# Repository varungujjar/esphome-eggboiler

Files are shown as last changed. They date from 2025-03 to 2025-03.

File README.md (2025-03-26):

# ESP Home based Egg Cooker

  
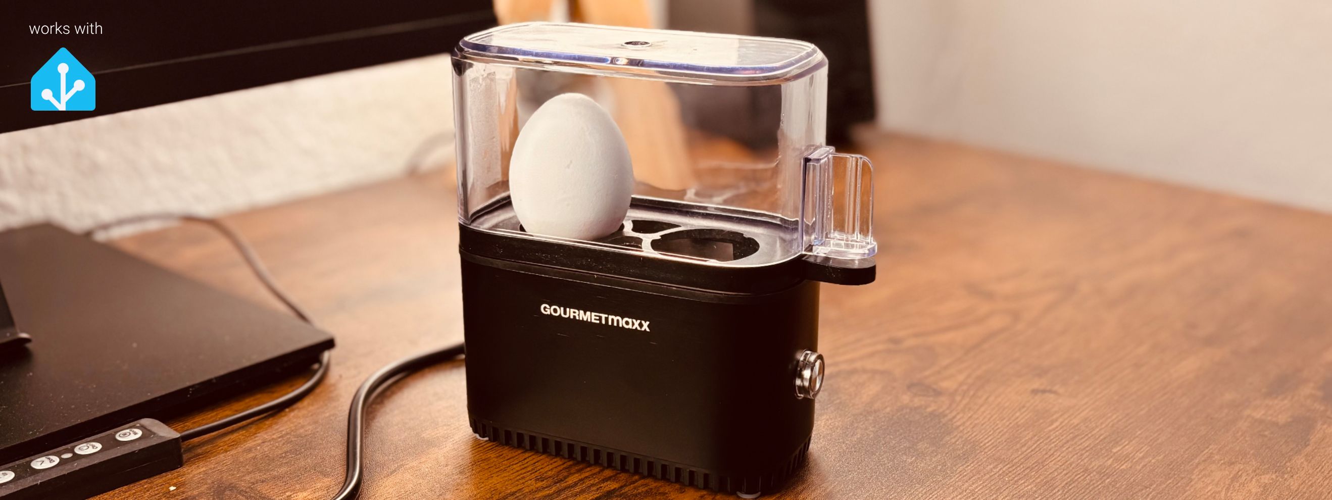
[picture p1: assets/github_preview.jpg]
App Screenshot
  

Smart Egg Cooker – Automate Your Breakfast Routine!

Upgrade your mornings with this intelligent Egg Cooker, designed to automate and perfect your breakfast routine. Equipped with a DS18B20 temperature sensor, it precisely monitors the boiling water, ensuring your eggs are cooked to perfection. A Piezo Buzzer alerts you when the cooker connects to WiFi and when your eggs are ready.

Seamlessly integrate it with Home Assistant for a smart home experience. Plus, with access to schematics and PCB Gerber files, you can fully customize and enhance its features to suit your needs.

Enjoy hassle-free, perfectly cooked eggs—every time!

## Features  

- Automate your morning breakfast routines with this egg cooker
- Temperature sensor using DS18B20 keeps track of the boiling water
- Piezo Buzzer plays sound when connected to Wifi & when egg is cooked
- Compatible with **Home Assistant** for seamless integration.  
- Access to schematics and PCB Gerber files.  
- Fully customizable for advanced features.  

## Requirements  

- **Home Assistant** (Standalone software version coming soon).  
- **USB-to-Serial Hardware** to program the ESP8266 12E.  
- **ESPHome Setup Guide**: [Getting Started with ESPHome](https://esphome.io/guides/getting_started_hassio.html).  

## Demo  
[Full Video](https://youtu.be/4700ta0FNh4).  

Follow us for more exciting projects and updates:  
  

## License  

This project is licensed under the **GPL-3.0 License**. [Learn More](https://www.gnu.org/licenses/gpl-3.0).

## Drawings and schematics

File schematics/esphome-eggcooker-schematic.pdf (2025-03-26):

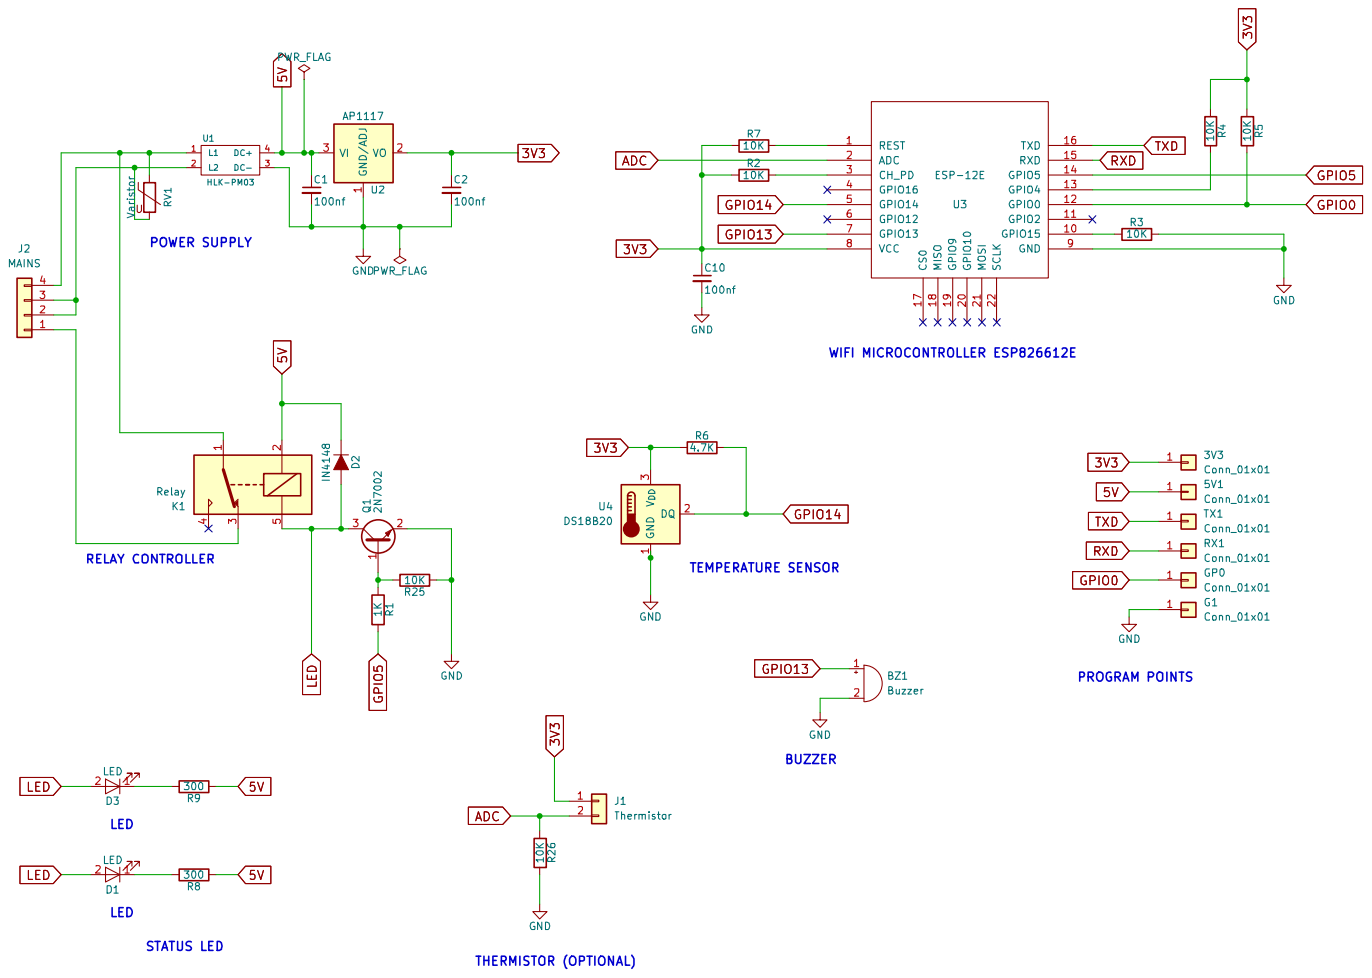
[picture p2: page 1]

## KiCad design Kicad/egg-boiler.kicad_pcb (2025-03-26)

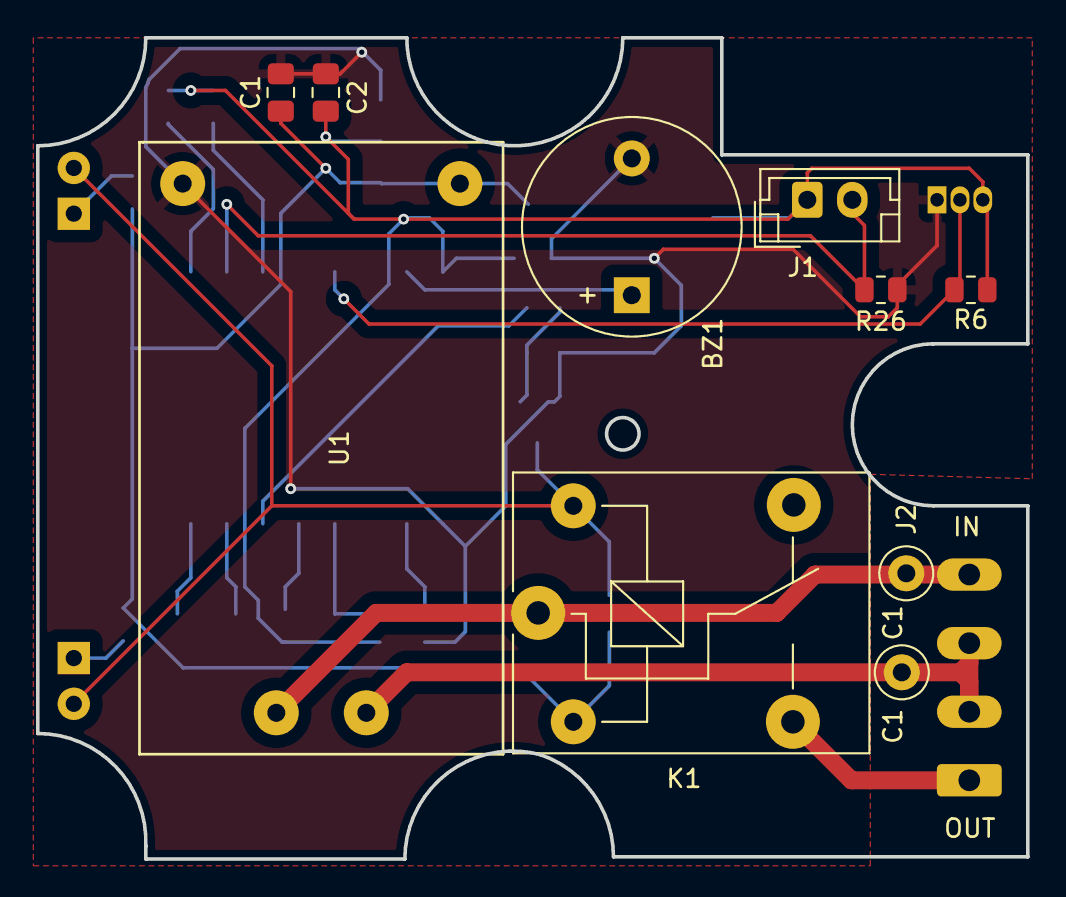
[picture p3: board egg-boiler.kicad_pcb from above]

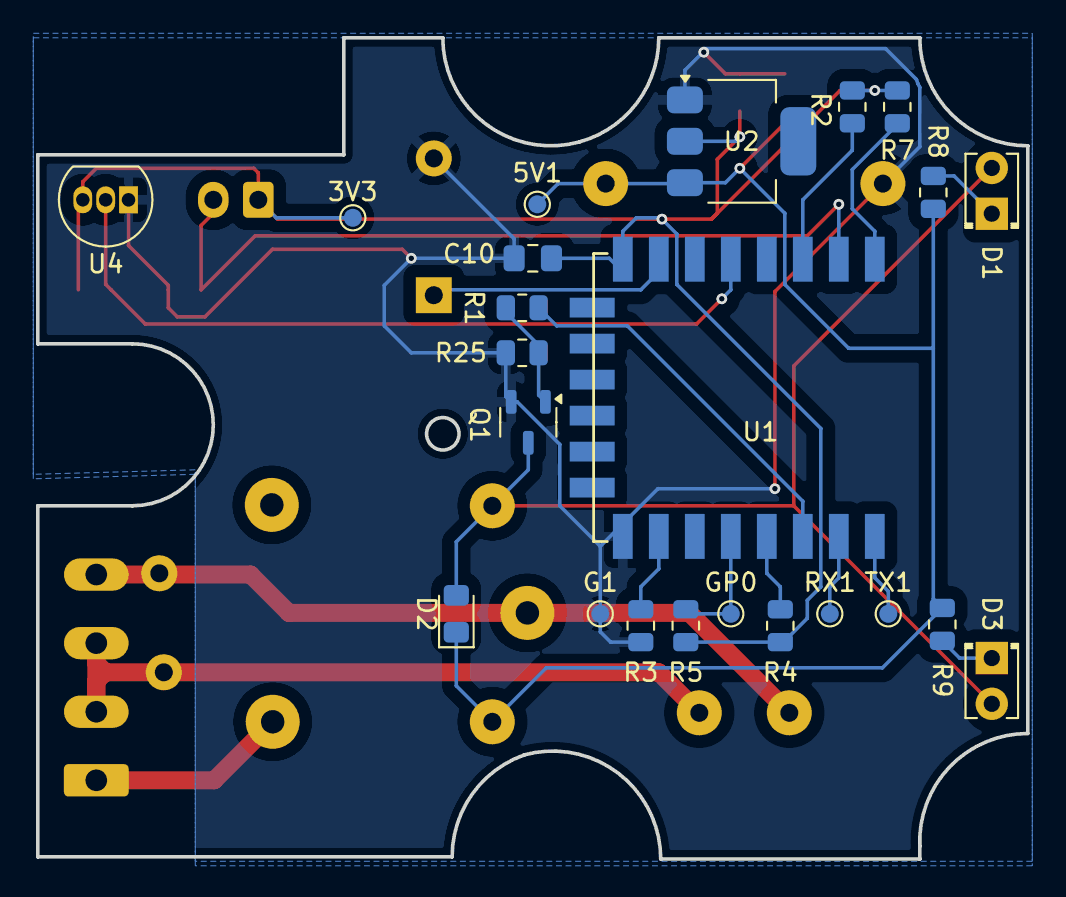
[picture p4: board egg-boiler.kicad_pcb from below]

Board: 2 copper layers, 55.0 x 45.6 mm, 34 parts (23 on the bottom side), 21 nets.

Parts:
3V3, 5V1: Conn_01x01; TestPoint_Pad_D1.0mm
BZ1: Buzzer; Buzzer_12x9.5RM7.6
C1, C1#2: C0; TestPoint_Loop_D1.80mm_Drill1.0mm_Beaded
C1#3, C2, C10: 100nf; C_0805_2012Metric_Pad1.18x1.45mm_HandSolder
D1, D3: LED; LED_D2.0mm_W4.0mm_H2.8mm_FlatTop
D2: IN4148; D_0805_2012Metric_Pad1.15x1.40mm_HandSolder
G1: Conn_01x01; TestPoint_Pad_D1.0mm
GP0: Conn_01x01; TestPoint_Pad_D1.0mm
J1: Thermistor; JST_EH_B2B-EH-A_1x02_P2.50mm_Vertical
J2: MAINS; PhoenixContact_MCV_1,5_4-G-3.81_1x04_P3.81mm_Vertical_Custom
K1: Relay; Relay_SPDT_SANYOU_SRD_Series_Form_C
Q1: 2N7002; SOT-23-3
R1: 1K; R_0805_2012Metric
R2, R3, R4, R5, R7, R25, R26: 10K; R_0805_2012Metric
R6: 4.7K; R_0805_2012Metric
R8, R9: 300; R_0805_2012Metric
RX1: Conn_01x01; TestPoint_Pad_D1.0mm
TX1: Conn_01x01; TestPoint_Pad_D1.0mm
U1: HLK-PM03; HLK-PM01
U1#2: ESP-12E; ESP-12E_SMD
U2: AP1117; SOT-223
U4: DS18B20; TO-92_Inline

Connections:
3V3: 3V3.1, C2.1, C10.1, J1.1, R2.1, R4.1, R5.1, R6.1, R7.1, U1#2.8 (VCC), U2.2 (VO), U4.3 (V_{DD})
5V: 5V1.1, C1#3.1, D2.1 (K), K1.2, R8.1, R9.1, U1.4 (DC+), U2.3 (VI)
ADC: J1.2, R26.1, U1#2.2 (ADC)
GND: BZ1.2 (-), C1#3.2, C2.2, C10.2, G1.1, Q1.2 (E), R3.2, R25.1, R26.2, U1.3 (DC-), U1#2.9 (GND), U2.1 (GND/ADJ), U4.1 (GND)
GPIO0: GP0.1, R5.2, U1#2.12 (GPIO0)
GPIO5: R1.2, U1#2.14 (GPIO5)
GPIO13: BZ1.1 (+), U1#2.7 (GPIO13)
GPIO14: R6.2, U1#2.5 (GPIO14), U4.2 (DQ)
LED: D1.2 (A), D2.2 (A), D3.2 (A), K1.5, Q1.3 (C)
unnamed: D1.1 (K), R8.2
unnamed: D3.1 (K), R9.2
unnamed: J2.1, K1.3
unnamed: J2.2, J2.3, U1.2 (L2)
unnamed: J2.4, K1.1, U1.1 (L1)
unnamed: Q1.1 (B), R1.1, R25.2
unnamed: R2.2, U1#2.3 (CH_PD)
unnamed: R4.2, U1#2.13 (GPIO4)
unnamed: R3.1, U1#2.10 (GPIO15)
unnamed: R7.2, U1#2.1 (REST)
RXD: RX1.1, U1#2.15 (RXD)
TXD: TX1.1, U1#2.16 (TXD)

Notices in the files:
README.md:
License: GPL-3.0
